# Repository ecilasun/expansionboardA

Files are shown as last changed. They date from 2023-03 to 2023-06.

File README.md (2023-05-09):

# expansionboardA

This repository contains KiCAD 7 project files for an expansion module built for QMTECH A7 200T core board.
Required libraries (models and symbols) are included with the project.

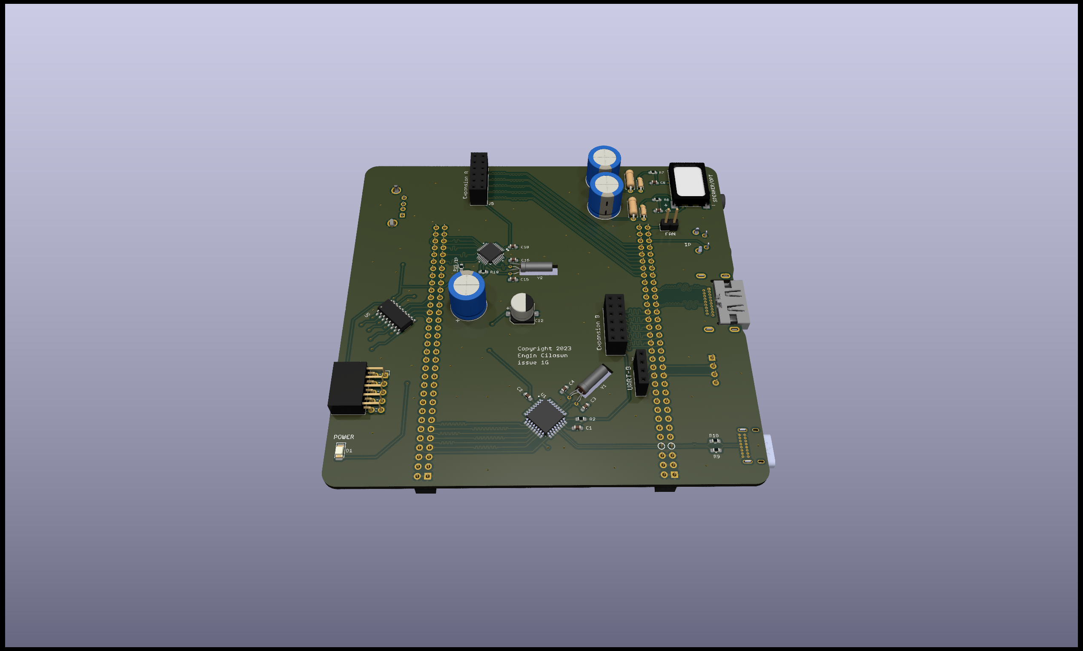
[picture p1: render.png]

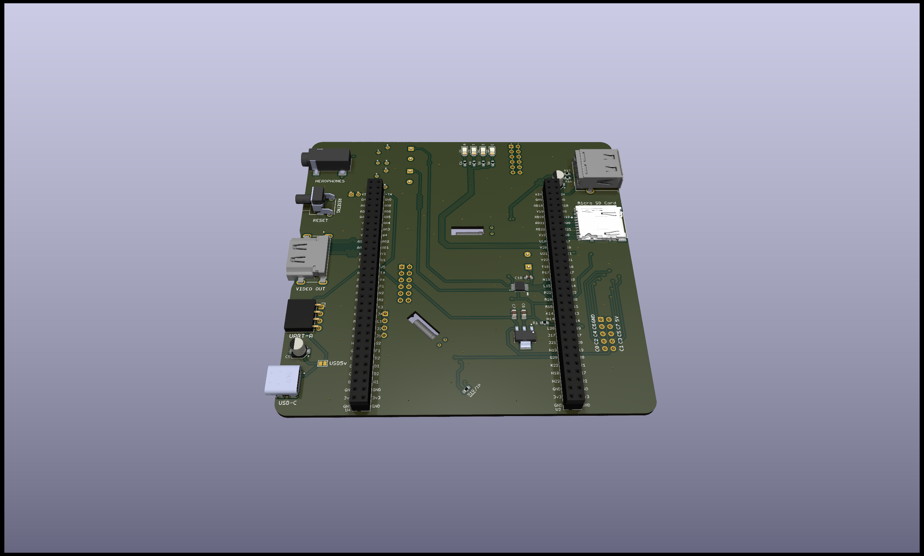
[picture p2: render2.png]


# Bill of materials

See expansionboardA.cv file for the list of components required for a fully populated board. Please note that some are optional (such as the USB controller chips) depending on your application.

# Default SoC, ROM image and samples

For hardware, visit https://github.com/ecilasun/tinysys. The project files require a recent version of Vivado suite to work.

For software, visit https://github.com/ecilasun/riscvtool and check the tinysys directory for the default ROM image and samples. The ROM image comes in two parts: the actual executable ROM and another one (fetch) that contains instruction sequences to inject on hardware/software interrupts. Samples demonstrate majority of the capabilities of the tinysys SoC itself.

# Device manual:
- Populating the board
    - USB-C power
    - Debug port
    - SD Card reader
    - HDMI port
    - A/D converter
    - USB-C client
    - USB-A host
    - Board carrier headers
    - Fan connection
    - Audio
    - QMTECH A7-200T core board
- Installing tinysys SoC bitware
- Compiling and running demo software on the board
    - Compiler toolchain installation
    - Hello, board!
- Operating system how-tos
    - List of syscalls
    - Memory layout
    - Operating principles
    - Debugging
- Device manuals:
    - Raw audio
    - OPL2 audio
    - GPU
    - DMA
    - A/D converter
    - Interrupt handling
    - Task system

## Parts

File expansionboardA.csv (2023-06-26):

Id | Designator | Footprint | Quantity | Designation | Supplier and ref
1 | C15,C16,C4,C3 | C_0603_1608Metric_Pad1.08x0.95mm_HandSolder | 4 | 18pf
2 | R10,R9,R15,R7,R8,R19,R16,R6,R4,R17,R3,R5 | R_0603_1608Metric_Pad0.98x0.95mm_HandSolder | 12 | R33_ohm
3 | C2,C18,C10 | C_0603_1608Metric_Pad1.08x0.95mm_HandSolder | 3 | 0.1uf
4 | R18,R2 | R_0603_1608Metric_Pad0.98x0.95mm_HandSolder | 2 | 10_kohm
5 | R14,R11 | R_Axial_DIN0207_L6.3mm_D2.5mm_P7.62mm_Horizontal | 2 | 10KOhm
6 | Y1,Y2 | Crystal_AT310_D3.0mm_L10.0mm_Horizontal | 2 | Crystal
7 | C12 | CP_Elec_6.3x5.9 | 1 | 10uf
8 | C9,C8,C1,C17 | C_0603_1608Metric_Pad1.08x0.95mm_HandSolder | 4 | 1uf ceramic
9 | J5,J6 | PinSocket_2x06_P2.54mm_Vertical | 2 | Conn_02x06_Odd_Even
10 | U7 | 21-0110-C_90-0149-32L_MXM | 1 | MAX3421EEHJ+T
11 | C11,C14,C13 | CP_Radial_D10.0mm_P5.00mm | 3 | 3.3uf
12 | J7 | PinSocket_1x04_P2.54mm_Vertical | 1 | DEBUG
13 | ADC1 | PinSocket_2x05_P2.54mm_Horizontal | 1 | Conn_01x10_Socket
14 | R13,R12 | R_Axial_DIN0204_L3.6mm_D1.6mm_P5.08mm_Horizontal | 2 | 470Ohm
15 | D1,D4,D5,D2,D3 | LED_1206_3216Metric_Pad1.42x1.75mm_HandSolder | 5 | LED
16 | LSRIGHT1 | SPKR_AS01508MS-SC11-WP-R | 1 | AS01508MS-SC11-WP-R
17 | J4 | PinHeader_1x02_P2.54mm_Vertical | 1 | FAN
18 | U1 | QFP80P900X900X160-32N | 1 | MAX3420EECJ
19 | U5 | SOIC127P600X175-16N | 1 | MCP3008T-I/SL
20 | R1 | R_0603_1608Metric_Pad0.98x0.95mm_HandSolder | 1 | 330 Ohm
21 | AU1 | CUI_SJ-3523-SMT-TR | 1 | SJ-3523-SMT-TR
22 | VR1 | VREG_LM1117MPX-3.3_NOPB | 1 | LM1117MPX-3.3/NOPB
23 | C5,C20 | CP_Elec_4x5.4 | 2 | 4.7uf
24 | U6 | CIR_3TSSOP-10 | 1 | CS4344-CZZR
25 | U2 | PinSocket_2x32_P2.54mm_Vertical | 1 | GPIO_U2
26 | U4 | PinSocket_2x32_P2.54mm_Vertical | 1 | GPIO_U4
27 | J1 | PinSocket_1x04_P2.54mm_Horizontal | 1 | DEBUG
28 | P1 | GCT_USB4085-GF-A_REVA4 | 1 | USB_C_Plug
29 | J3 | CUI_HD02-19-M-MSMT-TR | 1 | HDMI_A
30 | CRD1 | HRS_DM3AT-SF-PEJM5 | 1 | DM3AT-SF-PEJM5
31 | C6,C7 | C_0805_2012Metric_Pad1.18x1.45mm_HandSolder | 2 | 10 uf
32 | J2 | USB_A_Molex_67643_Horizontal | 1 | USB_A_Stacked
33 | RESETN1 | SW_1-1825027-1 | 1 | SW_Push
34 | JP4 | SolderJumper-2_P1.3mm_Open_Pad1.0x1.5mm | 1 | USB

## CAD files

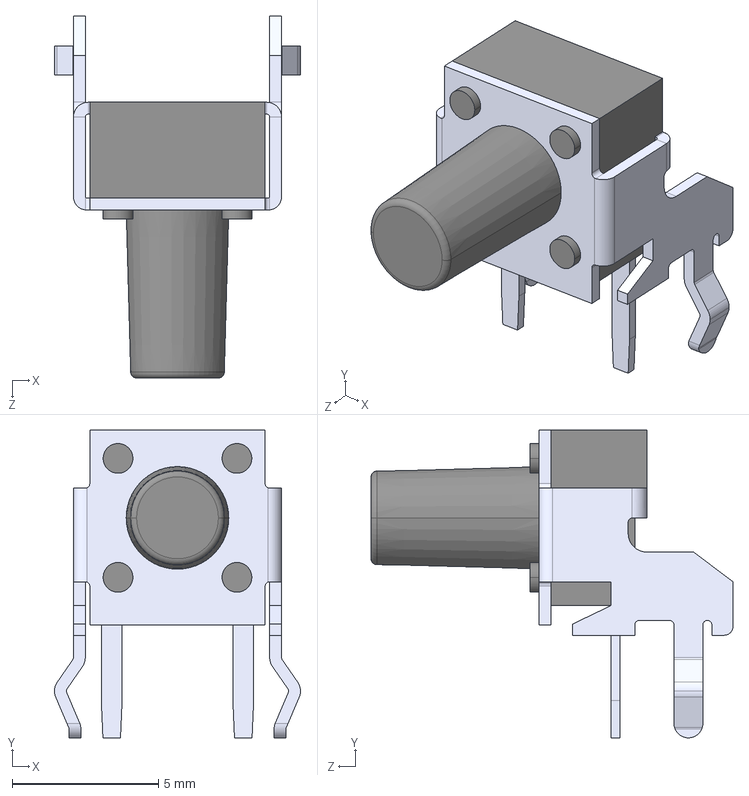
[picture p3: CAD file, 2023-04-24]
1_1825027_1/1-1825027-1.step
8.41 x 10.5 x 12.4 mm

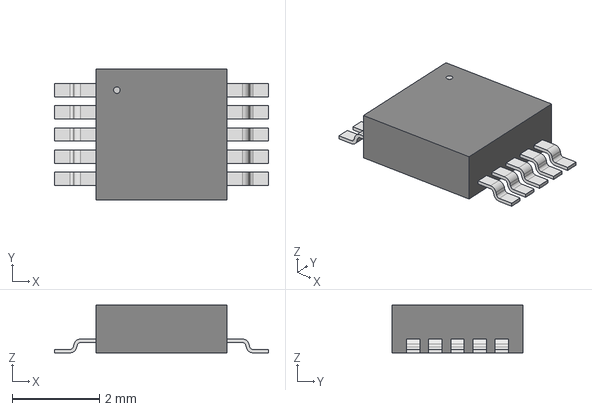
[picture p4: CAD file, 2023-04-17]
CS4344/CIR_3TSSOP-10.step
4.90 x 3.00 x 1.09 mm

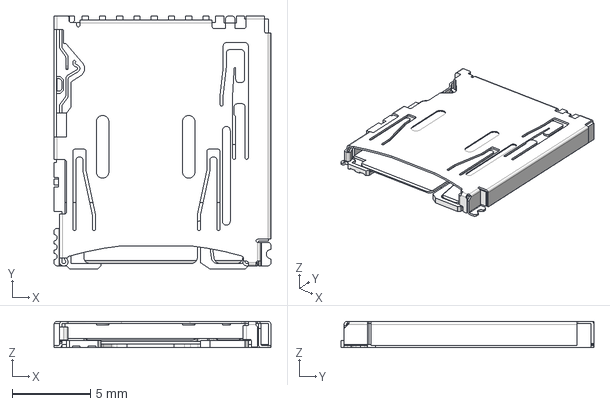
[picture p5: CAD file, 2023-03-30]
DM3AT-SF-PEJM5/DM3AT-SF-PEJM5.step
13.8 x 16.2 x 1.68 mm

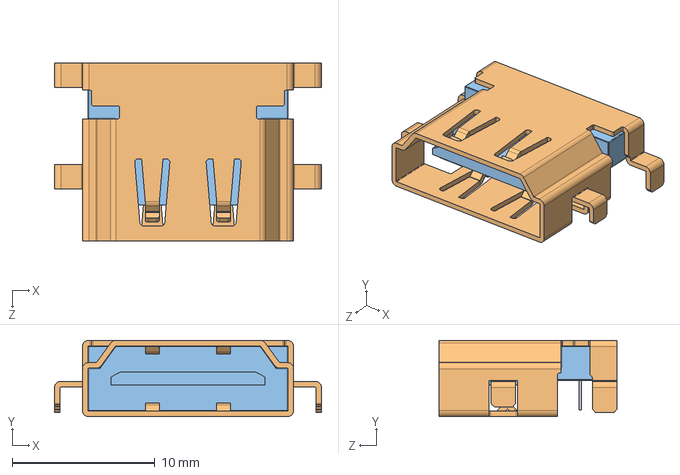
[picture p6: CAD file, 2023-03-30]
HD02-19-M-MSMT-TR/CUI_DEVICES_HD02-19-M-MSMT-TR.step
18.7 x 5.35 x 12.4 mm

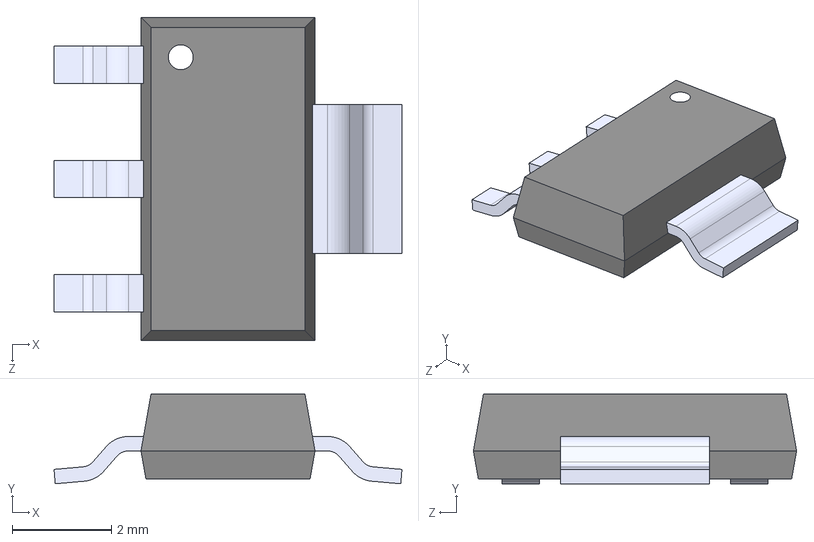
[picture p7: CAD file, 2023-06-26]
LM1117MPX33NOPB/LM1117MPX-3.3_NOPB.step
7.00 x 1.80 x 6.50 mm

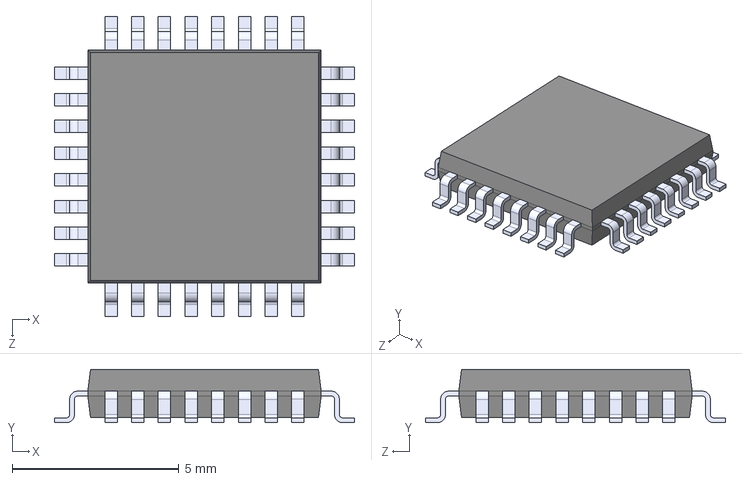
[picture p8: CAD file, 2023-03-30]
MAX3420EECJ/MAX3420EECJ.step
9.00 x 1.60 x 9.00 mm

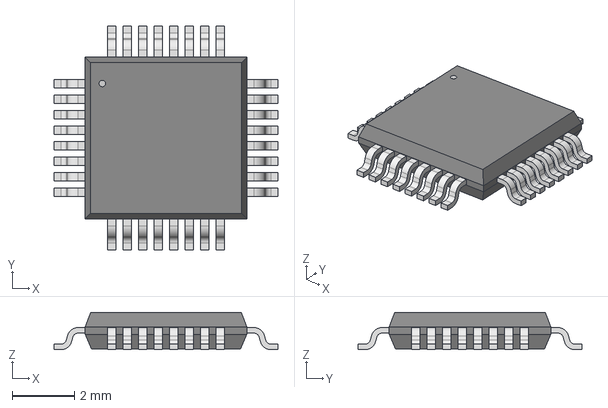
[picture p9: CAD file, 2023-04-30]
MAX3421EEHJ_T/21-0110-C_90-0149-32L_MXM.step
7.20 x 7.20 x 1.20 mm

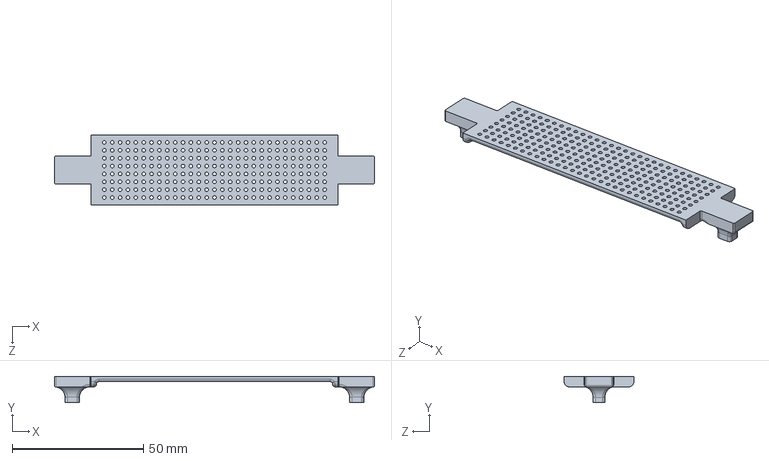
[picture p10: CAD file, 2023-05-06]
mechanical/carrier.SLDPRT
122.0 x 10.0 x 26.6 mm

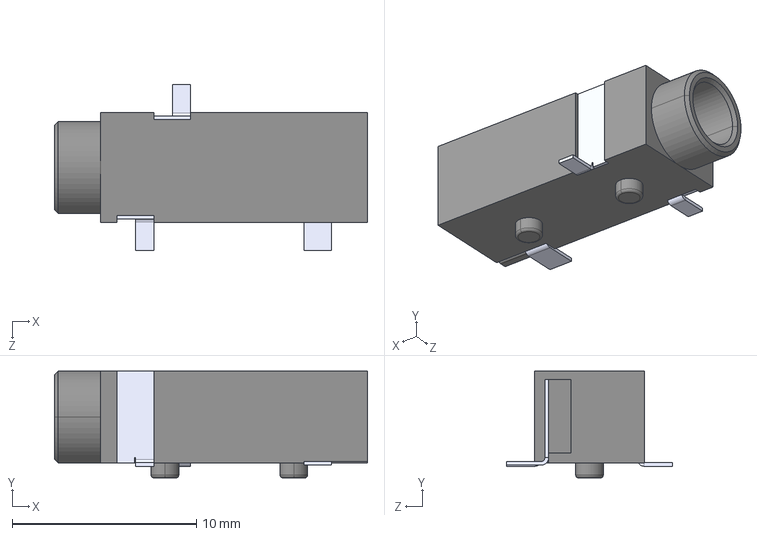
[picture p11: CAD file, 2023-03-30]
SJ-3523-SMT-TR/SJ-3523-SMT-TR.step
17.0 x 5.80 x 9.00 mm

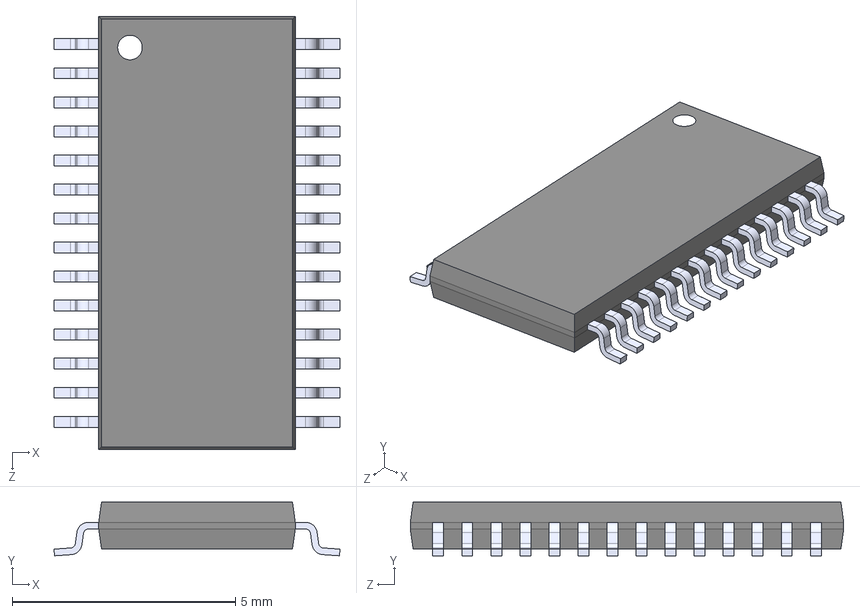
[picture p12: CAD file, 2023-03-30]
TLV320AIC23BIPW/TLV320AIC23BIPW.step
6.40 x 1.20 x 9.70 mm

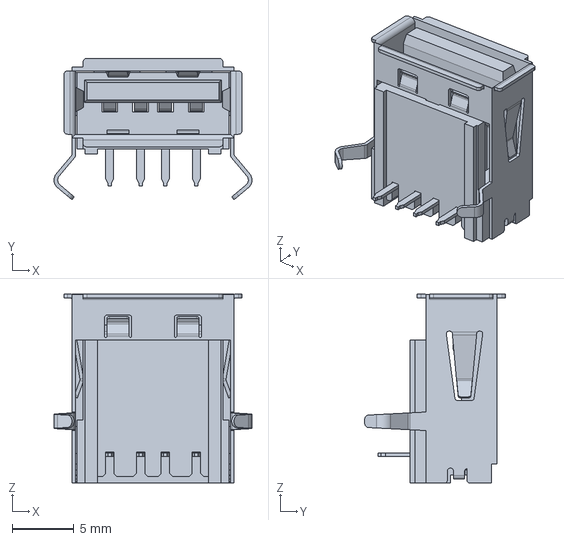
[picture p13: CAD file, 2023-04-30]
646430910/676430910.stp
16.0 x 11.4 x 15.3 mm

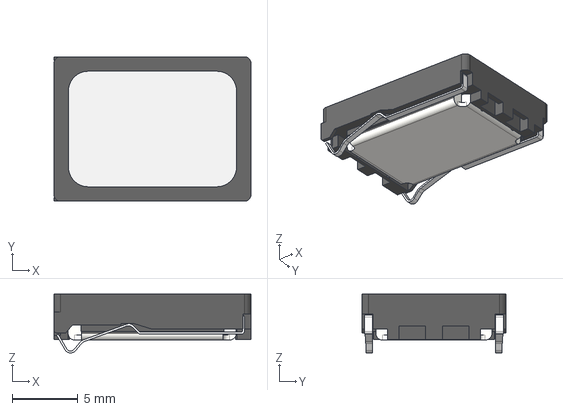
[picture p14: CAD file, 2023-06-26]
AS01508MS-SC11-WP-R/AS01508MS-SC11-WP-R.step
15.0 x 11.0 x 4.48 mm

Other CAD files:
MOLEX_676430910/676430910.stp

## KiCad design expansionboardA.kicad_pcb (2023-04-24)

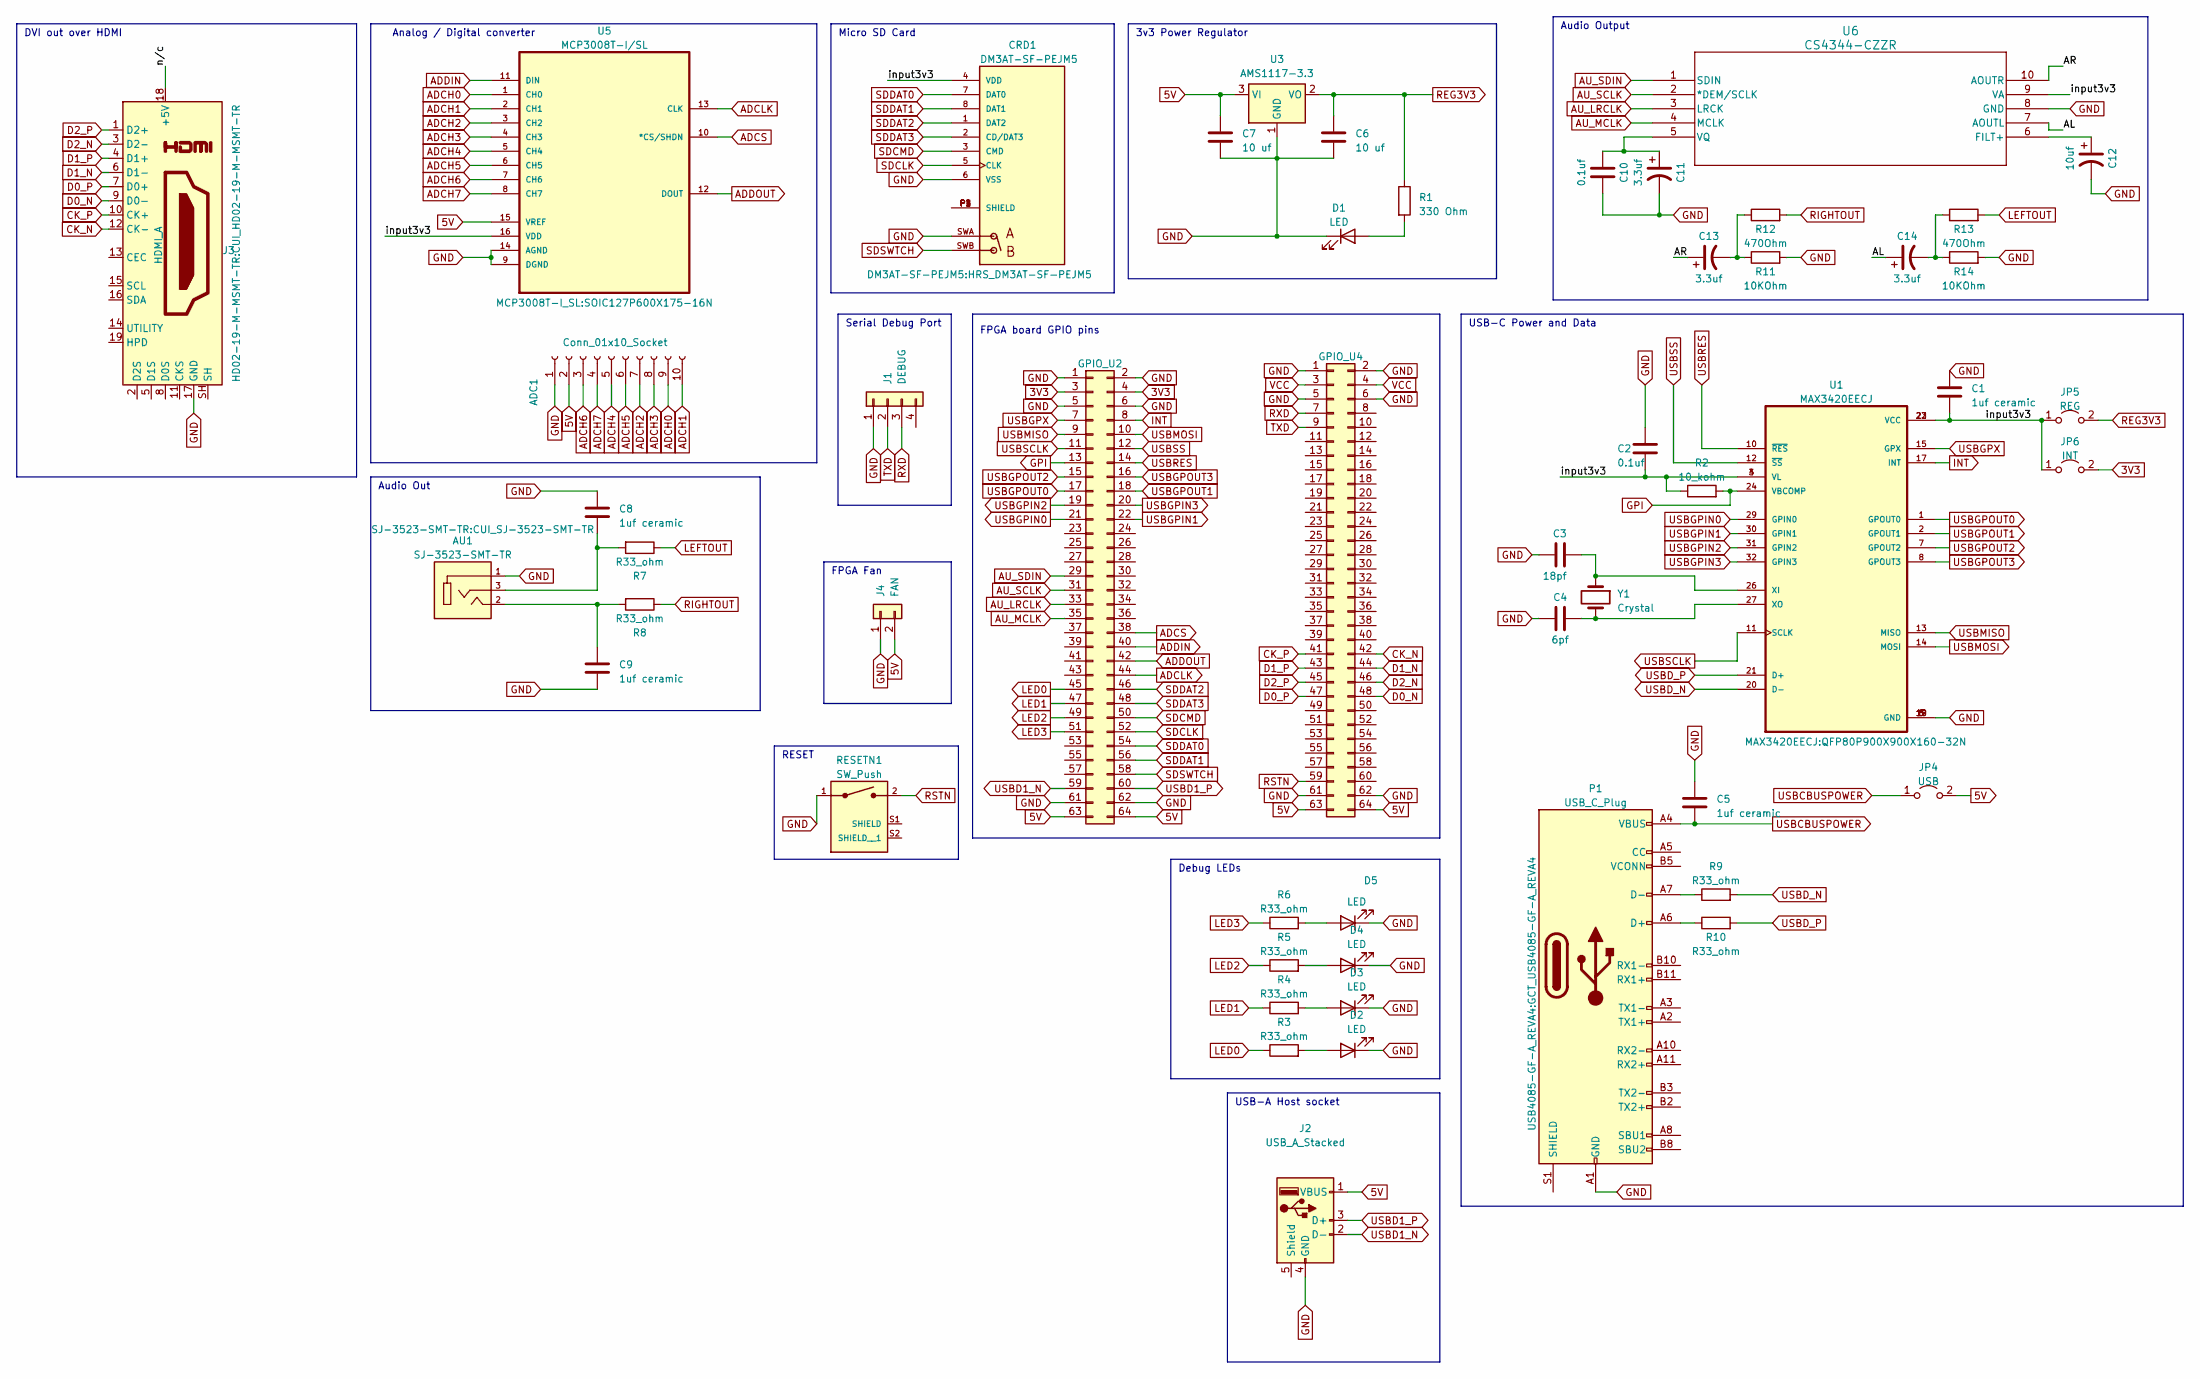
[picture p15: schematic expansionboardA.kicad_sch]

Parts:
ADC1: Conn_01x10_Socket; PinSocket_2x05_P2.54mm_Horizontal
AU1: SJ-3523-SMT-TR; CUI_SJ-3523-SMT-TR
C1, C5, C8, C9: 1uf ceramic; C_0603_1608Metric_Pad1.08x0.95mm_HandSolder
C2, C10: 0.1uf; C_0603_1608Metric_Pad1.08x0.95mm_HandSolder
C3: 18pf; C_0603_1608Metric_Pad1.08x0.95mm_HandSolder
C4: 6pf; C_0603_1608Metric_Pad1.08x0.95mm_HandSolder
C6, C7: 10 uf; C_0805_2012Metric_Pad1.18x1.45mm_HandSolder
C11, C13, C14: 3.3uf; CP_Radial_D10.0mm_P5.00mm
C12: 10uf; CP_Elec_6.3x5.9
CRD1: DM3AT-SF-PEJM5; HRS_DM3AT-SF-PEJM5
D1, D2, D3, D4, D5: LED; LED_1206_3216Metric_Pad1.42x1.75mm_HandSolder
J1: DEBUG; PinSocket_1x04_P2.54mm_Horizontal
J2: USB_A_Stacked; USB_A_Molex_67643_Horizontal
J3: HDMI_A; CUI_HD02-19-M-MSMT-TR
J4: FAN; PinHeader_1x02_P2.54mm_Vertical
JP4: USB; SolderJumper-2_P1.3mm_Open_Pad1.0x1.5mm
JP5: REG; SolderJumper-2_P1.3mm_Open_Pad1.0x1.5mm
JP6: INT; SolderJumper-2_P1.3mm_Open_Pad1.0x1.5mm
P1: USB_C_Plug; GCT_USB4085-GF-A_REVA4
R1: 330 Ohm; R_0603_1608Metric_Pad0.98x0.95mm_HandSolder
R2: 10_kohm; R_0603_1608Metric_Pad0.98x0.95mm_HandSolder
R3, R4, R5, R6, R7, R8, R9, R10: R33_ohm; R_0603_1608Metric_Pad0.98x0.95mm_HandSolder
R11, R14: 10KOhm; R_Axial_DIN0207_L6.3mm_D2.5mm_P7.62mm_Horizontal
R12, R13: 470Ohm; R_Axial_DIN0204_L3.6mm_D1.6mm_P5.08mm_Horizontal
RESETN1: SW_Push; SW_1-1825027-1; PARTREV G4
U1: MAX3420EECJ; QFP80P900X900X160-32N
U2: GPIO_U2; PinSocket_2x32_P2.54mm_Vertical
U3: AMS1117-3.3; SOT-89-3_Handsoldering
U4: GPIO_U4; PinSocket_2x32_P2.54mm_Vertical
U5: MCP3008T-I/SL; SOIC127P600X175-16N; MPN MCP3008T-I/SL
U6: CS4344-CZZR; CIR_3TSSOP-10
Y1: Crystal; Crystal_AT310_D3.0mm_L10.0mm_Horizontal

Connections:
3V3: JP6.2 (B), U2.3, U2.4
5V: ADC1.2, C7.1, J2.1 (VBUS), J4.2, JP4.2 (B), U2.63, U2.64, U3.3 (VI), U4.63, U4.64, U5.15 (VREF)
/AL: C14.1, U6.7 (AOUTL)
/AR: C13.1, U6.10 (AOUTR)
/input3v3: C1.2, C2.2, CRD1.4 (VDD), JP5.1 (A), JP6.1 (A), R2.1, U1.3 (VL), U1.4 (VL), U1.22 (VCC), U1.23 (VCC), U5.16 (VDD), U6.9 (VA)
/n/c: J3.18 (+5V)
ADCH0: ADC1.9, U5.1 (CH0)
ADCH1: ADC1.10, U5.2 (CH1)
ADCH2: ADC1.7, U5.3 (CH2)
ADCH3: ADC1.8, U5.4 (CH3)
ADCH4: ADC1.5, U5.5 (CH4)
ADCH5: ADC1.6, U5.6 (CH5)
ADCH6: ADC1.3, U5.7 (CH6)
ADCH7: ADC1.4, U5.8 (CH7)
ADCLK: U2.44, U5.13 (CLK)
ADCS: U2.38, U5.10 (*CS/SHDN)
ADDIN: U2.40, U5.11 (DIN)
ADDOUT: U2.42, U5.12 (DOUT)
AU_LRCLK: U2.33, U6.3 (LRCK)
AU_MCLK: U2.35, U6.4 (MCLK)
AU_SCLK: U2.31, U6.2 (*DEM/SCLK)
AU_SDIN: U2.29, U6.1 (SDIN)
CK_N: J3.12 (CK-), U4.42
CK_P: J3.10 (CK+), U4.41
D0_N: J3.9 (D0-), U4.48
D0_P: J3.7 (D0+), U4.47
D1_N: J3.6 (D1-), U4.44
D1_P: J3.4 (D1+), U4.43
D2_N: J3.3 (D2-), U4.46
D2_P: J3.1 (D2+), U4.45
GND: ADC1.1, AU1.1, C1.1, C2.1, C3.1, C4.1, C5.1, C6.2, C7.2, C8.1, C9.2, C10.2, C11.2, C12.2, CRD1.6 (VSS), CRD1.SWA, D1.1 (K), D2.1 (K), D3.1 (K), D4.1 (K), D5.1 (K), J1.1, J2.4 (GND), J3.17 (GND), J4.1, P1.A1 (GND), P1.A12 (GND), P1.B1 (GND), P1.B12 (GND), R11.2, R14.2, RESETN1.1, U1.5 (GND), U1.6 (GND), U1.18 (GND), U1.19 (GND), U2.1, U2.2, U2.5, U2.6, U2.61, U2.62, U3.1 (GND), U4.1, U4.2, U4.5, U4.6, U4.61, U4.62, U5.9 (DGND), U5.14 (AGND), U6.8 (GND)
GPI: R2.2, U1.24 (VBCOMP), U2.13
INT: U1.17 (INT), U2.8
LED0: R3.1, U2.45
LED1: R4.1, U2.47
LED2: R5.1, U2.49
LED3: R6.1, U2.51
LEFTOUT: R7.1, R13.2
unnamed: AU1.2, C9.1, R8.2
unnamed: AU1.3, C8.2, R7.2
unnamed: C13.2, R11.1, R12.1
unnamed: C14.2, R13.1, R14.1
unnamed: CRD1.P1 (SHIELD), CRD1.P2 (SHIELD), CRD1.P3 (SHIELD), CRD1.P4 (SHIELD)
unnamed: D1.2 (A), R1.2
unnamed: D2.2 (A), R3.2
unnamed: D3.2 (A), R4.2
unnamed: D4.2 (A), R5.2
unnamed: D5.2 (A), R6.2
unnamed: P1.A6 (D+), R10.1
unnamed: P1.A7 (D-), R9.1
unnamed: C3.2, U1.26 (XI), Y1.1
unnamed: C4.2, U1.27 (XO), Y1.2
unnamed: C12.1, U6.6 (FILT+)
unnamed: C10.1, C11.1, U6.5 (VQ)
REG3V3: C6.1, JP5.2 (B), R1.1, U3.2 (VO)
RIGHTOUT: R8.1, R12.2
RSTN: RESETN1.2, U4.59
RXD: J1.3, U4.7
SDCLK: CRD1.5 (CLK), U2.52
SDCMD: CRD1.3 (CMD), U2.50
SDDAT0: CRD1.7 (DAT0), U2.54
SDDAT1: CRD1.8 (DAT1), U2.56
SDDAT2: CRD1.1 (DAT2), U2.46
SDDAT3: CRD1.2 (CD/DAT3), U2.48
SDSWTCH: CRD1.SWB, U2.58
TXD: J1.2, U4.9
USBCBUSPOWER: C5.2, JP4.1 (A), P1.A4 (VBUS), P1.A9 (VBUS), P1.B4 (VBUS), P1.B9 (VBUS)
USBD1_N: J2.2 (D-), U2.59
USBD1_P: J2.3 (D+), U2.60
USBD_N: R9.2, U1.20 (D-)
USBD_P: R10.2, U1.21 (D+)
USBGPIN0: U1.29 (GPIN0), U2.21
USBGPIN1: U1.30 (GPIN1), U2.22
USBGPIN2: U1.31 (GPIN2), U2.19
USBGPIN3: U1.32 (GPIN3), U2.20
USBGPOUT0: U1.1 (GPOUT0), U2.17
USBGPOUT1: U1.2 (GPOUT1), U2.18
USBGPOUT2: U1.7 (GPOUT2), U2.15
USBGPOUT3: U1.8 (GPOUT3), U2.16
USBGPX: U1.15 (GPX), U2.7
USBMISO: U1.13 (MISO), U2.9
USBMOSI: U1.14 (MOSI), U2.10
USBRES: U1.10 (~RES), U2.14
USBSCLK: U1.11 (SCLK), U2.11
USBSS: U1.12 (~SS), U2.12
VCC: U4.3, U4.4

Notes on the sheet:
Serial Debug Port
Audio Output
USB-A Host socket
FPGA board GPIO pins
Micro SD Card
USB-C Power and Data
Debug LEDs
Audio Out
RESET
3v3 Power Regulator
DVI out over HDMI
FPGA Fan
Analog / Digital converter

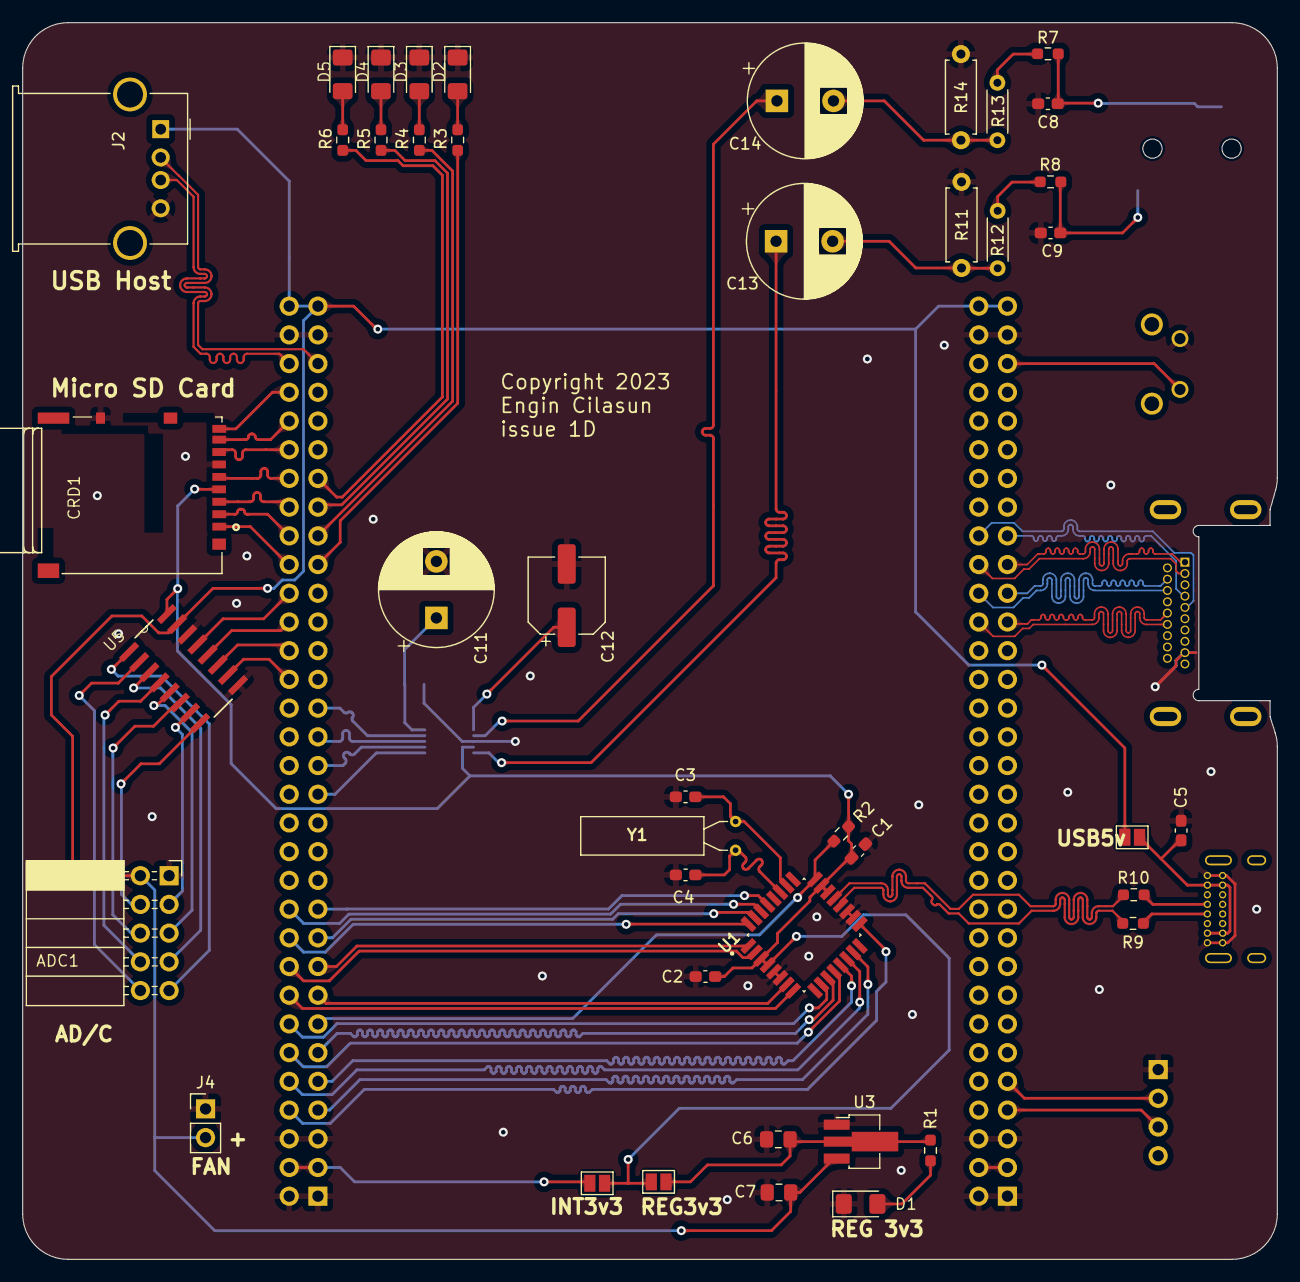
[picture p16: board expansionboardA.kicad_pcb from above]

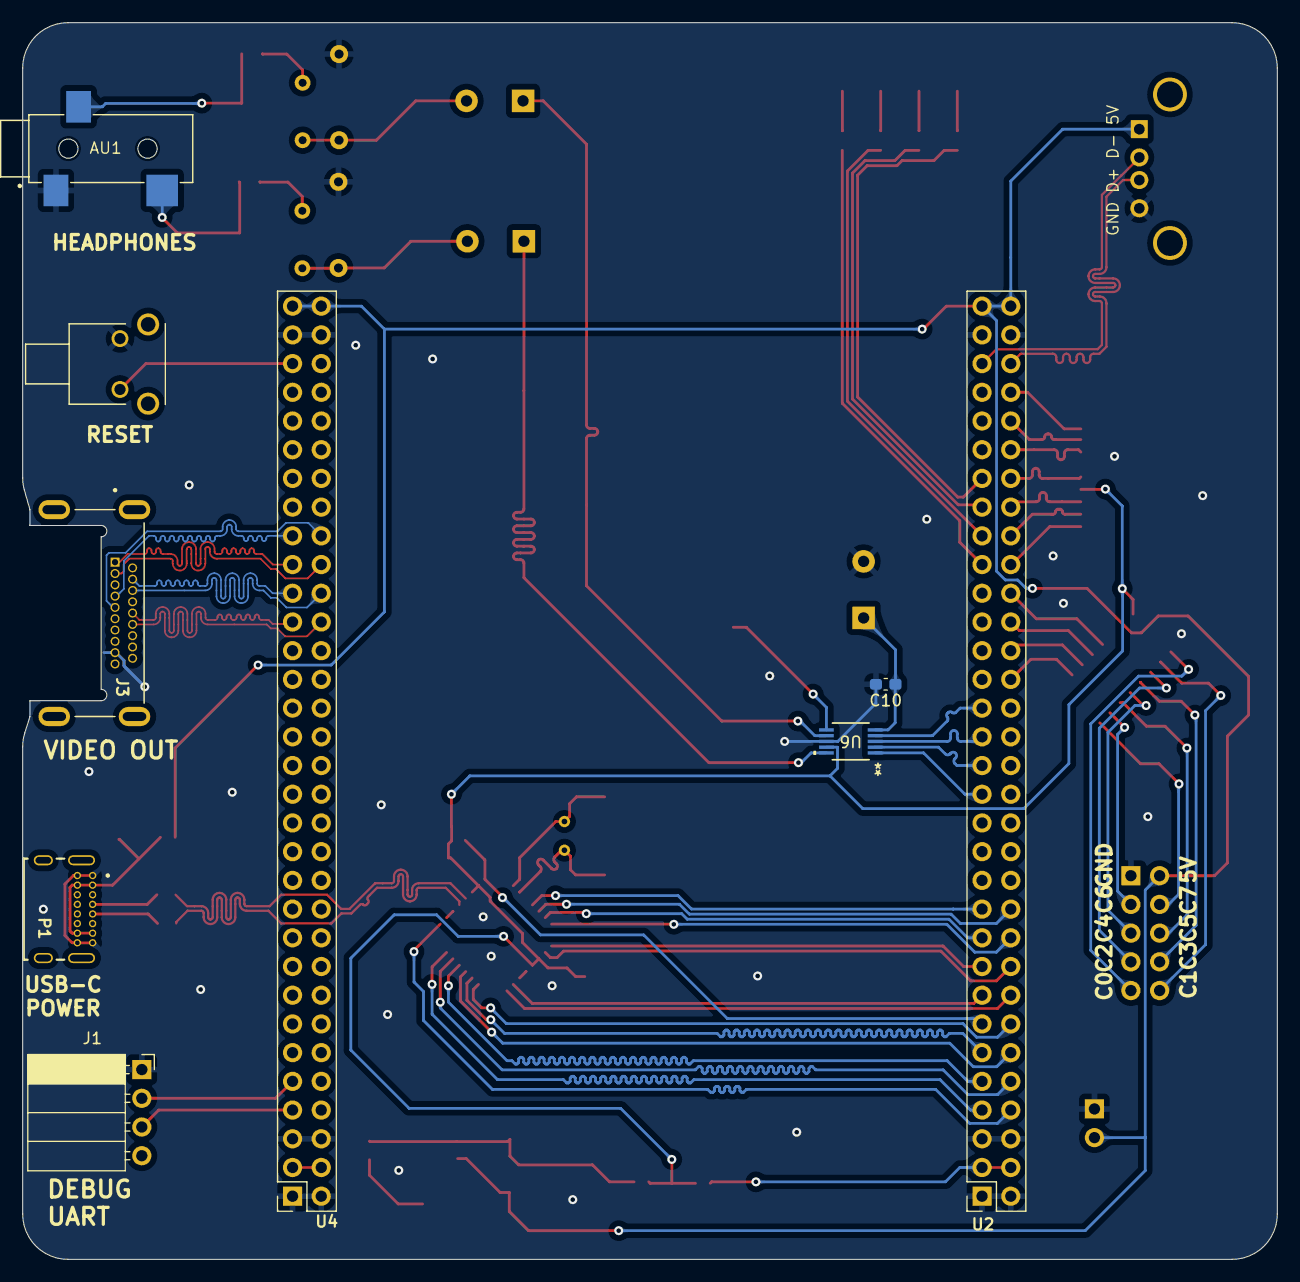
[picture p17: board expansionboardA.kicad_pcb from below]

Board: 2 copper layers, 111.0 x 109.4 mm, 52 parts (9 on the bottom side), 85 nets.

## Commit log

2023-03-30 Initial submit
    [CUI_DEVICES_HD02-19-M-MSMT-TR.step, DM3AT-SF-PEJM5.step, MAX3420EECJ.step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]
2023-03-30 Small layout edits
    [expansionboardA.csv, expansionboardA.kicad_pcb]
2023-03-31 Board updated
    [expansionboardA.kicad_pcb, expansionboardA.kicad_sch]
2023-03-31 Updated schematic with correct parts Built gerber files
    [expansionboardA-B_Cu.gbr, expansionboardA-B_Mask.gbr, expansionboardA-B_Paste.gbr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]
2023-03-31 Copied bill of materials CVS file
2023-03-31 Updated board with USB A host connector
    [676430910.stp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]
2023-03-31 Updated bill of materials
    [expansionboardA.csv]
2023-04-07 Exported board step file
2023-04-11 Updated board
    [expansionboardA.kicad_pcb, expansionboardA.kicad_sch]
2023-04-17 Updatre board version
    [CIR_3TSSOP-10.step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]
2023-04-17 Updated board files
    [expansionboardA-B_Cu.gbr, expansionboardA-B_Mask.gbr, expansionboardA-B_Paste.gbr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]
2023-04-19 Updated board to fix some issues
    [expansionboardA-B_Cu.gbr, expansionboardA-B_Mask.gbr, expansionboardA-B_Paste.gbr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]
2023-04-23 Updated to new board version
    [expansionboardA.kicad_pcb, expansionboardA.kicad_sch]
2023-04-24 Updated board image
2023-04-24 Rebuilt board
    [expansionboardA-B_Cu.gbr, expansionboardA-B_Mask.gbr, expansionboardA-B_Paste.gbr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]
2023-04-28 Board updates
    [expansionboardA-B_Cu.gbr, expansionboardA-B_Mask.gbr, expansionboardA-B_Paste.gbr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]
2023-04-30 Adding USB host chip
    [21-0110-C_90-0149-32L_MXM.step, 676430910.stp, expansionboardA.kicad_sch]
2023-04-30 Mechanical bits
    [carrier.SLDPRT]
2023-05-06 Fixed some errors on the board
    [expansionboardA-B_Cu.gbr, expansionboardA-B_Mask.gbr, expansionboardA-B_Paste.gbr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]
2023-05-08 Cleaned up board layout
    [expansionboardA-B_Cu.gbr, expansionboardA-B_Mask.gbr, expansionboardA-B_Paste.gbr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]
2023-05-08 Updated board traces
    [expansionboardA-B_Cu.gbr, expansionboardA-B_Mask.gbr, expansionboardA-B_Paste.gbr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]
2023-05-08 Updat4ed some routing
    [expansionboardA-B_Cu.gbr, expansionboardA-B_Mask.gbr, expansionboardA-B_Paste.gbr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]
2023-05-09 Board changes
    [expansionboardA-B_Cu.gbr, expansionboardA-B_Mask.gbr, expansionboardA-B_Paste.gbr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]
2023-05-28 Smoothed traces
2023-05-29 Some modifications for mount holes and expansion port Also added optional pullup resistors
    [expansionboardA-B_Cu.gbr, expansionboardA-B_Mask.gbr, expansionboardA-B_Paste.gbr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]
2023-06-26 Updated board file with new power regulator
    [AS01508MS-SC11-WP-R.step, LM1117MPX-3.3_NOPB.step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]

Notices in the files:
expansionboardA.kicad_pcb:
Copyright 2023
